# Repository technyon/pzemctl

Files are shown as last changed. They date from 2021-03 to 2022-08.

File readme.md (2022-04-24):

# pzem energy monitor firmware

# About

This is the source code for a three phase energy monitor based upon three pzem-004t modules. It reads energy values from those modules and sends them over LAN to an mqtt server. Optionally, values can be displayed on an SSD1306 display.
The included 3D printable space houses all required hardware.

# A word of caution

The pzem-004t modules used need to be connected to mains power. Mains power is dangerous and there's danger to receive a potentially lethal electric shock. Furthermore, fire can be the result of incorrectly connecting the modules.  Only connect the pzem-004t if you know what you are doing! If not, ask someone who does.

Also, please read the paragraph about liability in the provided LICENSE file.

# Hardware
### Required
- Arduino Mega 2560
- W5500 LAN Module (https://www.az-delivery.de/en/products/w5500-ethernet-netzwerk-internet-modul-fuer-arduino)

### Optional
- SSD1306 Display (https://www.amazon.de/gp/product/B0777HHQDT)
- Push buttons to control display (https://www.amazon.de/gp/product/B07DJ8QMB1). Other buttons can be used of course, Fusion 360 file is included to modify enclosure.
- Relay card to control external appliance
- 3 LEDs

# Compilation

### Prerequisites
- Arduino SDK. Unpack and set ARDUINO_SDK_PATH to its location (e. g. export ARDUINO_SDK_PATH="/usr/share/arduino-1.8.13/")
- Arduino cmake toolchain: https://github.com/a9183756-gh/Arduino-CMake-Toolchain/. Unpack to a location of your choice
- cmake
- avr-gcc

### Running cmake

In the pzemctl directory, create a cmake build directory in change into it.

- cmake -D CMAKE_TOOLCHAIN_FILE=/path/to/Arduino-CMake-Toolchain/Arduino-toolchain.cmake ..
- Run make

cmake should now be setup. Run make to compile.

# Wiring

- Connect pzem-004t modules to Mega uart ports 1-3 (Mega pins 14-19)
- connect W5500 LAN module to SPI PINS (Mega pins 50-53)
- connect W5500 CS pin to Mega Pin 53
- connect W5500 Reset pin to Mega Pin 49
- connect display to Mega I2C pins (optional; Mega pins 20 and 21)
- Connect LEDs to Mega pins 5-8 (optional; PIN 7 is for network status)
- Connect Buttons to GND and Mega pins 44-48 (optional)

# Enclosure

The enclosure is seperated into two levels. The bottom levels holds the pzem-004t modules. Use M3 ~4mm screws.
The upper layer has room for the Arduino mega and the W5500 module. Again, uses M3 screws. Optionally, 3 LEDs can be mounted here. They point inside the case, I used white PETG so they can shine through.
The lid allows to mount the display (use M2 screws and nut) and the buttons.

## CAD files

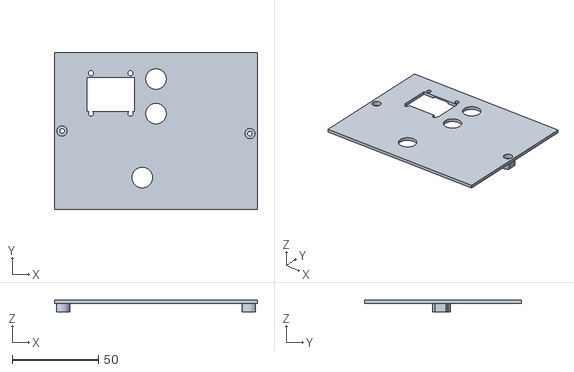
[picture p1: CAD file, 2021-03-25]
enclosure/pzem004t Top.stl
118.0 x 91.0 x 7.00

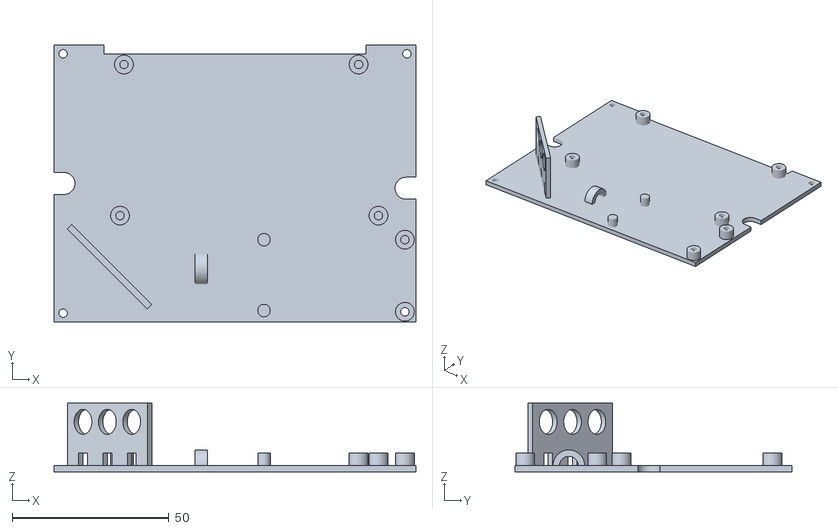
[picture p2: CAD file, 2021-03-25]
enclosure/pzem004t Middle.stl
115.6 x 88.6 x 22.0

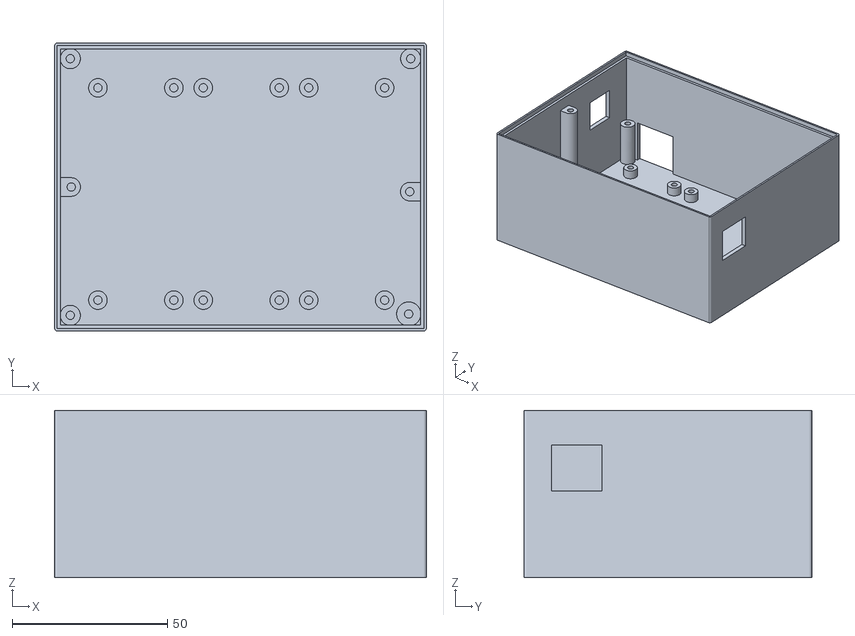
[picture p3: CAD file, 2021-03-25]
enclosure/pzem004t Bottom.stl
120.0 x 93.0 x 54.0

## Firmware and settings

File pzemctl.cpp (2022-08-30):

// Including Arduino.h is required for using Serial functions
#include <Arduino.h>
#include <SPI.h>
#include <HardwareSerial.h>
#include "Pzem004t.h"
#include "Network.h"
#include <src/Arduino_FreeRTOS.h>
#include <src/task.h>
#include "DisplaySSD1306.h"
#include "Led.h"
#include "Input.h"
#include "WebServer.h"
#include "EepromConfiguration.h"
#include "Config.h"


EepromConfiguration* configuration;
hw::Pzem004t* pzem;
hw::Input* input;
hw::DisplaySSD1306* display;
Network *nw;
web::WebServer* webServer;
hw::Led led;

hw::pzem004tvalues phasesCombined;
hw::pzem004tvalues phase1Values;
hw::pzem004tvalues phase2Values;
hw::pzem004tvalues phase3Values;

bool setupModeRequested = false;
bool setupModeEnabled = false;

bool switchState = false;
uint8_t displayUpdateCounter = 0;

void setupMode()
{
    setupModeEnabled = true;
    Serial.println(F("SETUP"));
    display->showMessage("Starting\nSetup");
    nw->enableConfigMode();

    IPAddress ip = nw->ipAddress();
    char message[18];
    sprintf(message, "%i.%i.%i.%i", ip[0], ip[1], ip[2], ip[3]);
    display->showMessage(message);

    webServer->enable();
    while(webServer->enabled() && setupModeEnabled)
    {
        vTaskDelay( 500 / portTICK_PERIOD_MS);
    }
    if(setupModeEnabled)
    {
        display->showMessage("Configu\nsaved");
    }
    else
    {
        display->showMessage("Setup\ncancelled");
    }

    webServer->disable();
    nw->disableConfigMode();
    vTaskDelay(2000 / portTICK_PERIOD_MS);
    display->clearMessage();

    setupModeEnabled = false;
}

void TaskPollPzem(void *pvParameters)
{
    while(true)
    {
        pzem->update();

        phase1Values = pzem->values1();
        phase2Values = pzem->values2();
        phase3Values = pzem->values3();

        phasesCombined.voltage = (phase1Values.voltage + phase2Values.voltage + phase3Values.voltage) / (float)3;
        phasesCombined.current = phase1Values.current + phase2Values.current + phase3Values.current;
        phasesCombined.power = phase1Values.power + phase2Values.power + phase3Values.power;
        phasesCombined.energy = phase1Values.energy + phase2Values.energy + phase3Values.energy;
        phasesCombined.frequency = (phase1Values.frequency + phase2Values.frequency + phase3Values.frequency) / (float)3;
        phasesCombined.pf = (phase1Values.pf + phase2Values.pf + phase3Values.pf) / 3;
        phasesCombined.error = phase1Values.error || phase2Values.error || phase3Values.error;

        vTaskDelay( 100 / portTICK_PERIOD_MS);
    }
}

void TaskInputAndDisplay(void *pvParameters)
{
    while(true)
    {
        input->update();
        displayUpdateCounter++;
        if(displayUpdateCounter >= 4)
        {
            displayUpdateCounter = 0;
            display->update(phasesCombined, phase1Values, phase2Values, phase3Values);
        }
        vTaskDelay( 20 / portTICK_PERIOD_MS);
    }
}

void TaskNetwork(void *pvParameters)
{
    while(true)
    {
        webServer->update();
        nw->update(phasesCombined, phase1Values, phase2Values, phase3Values);

        vTaskDelay( 100 / portTICK_PERIOD_MS);
    }
}

void TaskSetupMode(void *pvParameters)
{
    while(true)
    {
        if(setupModeRequested)
        {
            setupModeRequested = false;
            if(!setupModeEnabled)
            {
                setupMode();
            }
        }

        vTaskDelay( 200 / portTICK_PERIOD_MS);
    }
}

void setupTasks()
{
    xTaskCreate(
            TaskPollPzem
            ,  "Pzm"
            ,  64
            ,  NULL
            ,  2
            ,  NULL );

    xTaskCreate(
            TaskInputAndDisplay
            ,  "Dsp"
            ,  256
            ,  NULL
            ,  0
            ,  NULL );

    xTaskCreate(
            TaskNetwork
            ,  "Nw"
            ,  1024
            ,  NULL
            ,  1
            ,  NULL );

    xTaskCreate(
            TaskSetupMode
            ,  "Setup"
            ,  448
            ,  NULL
            ,  0
            ,  NULL );
}

void setSwitchState(bool value, bool showMessage)
{
    if(switchState == value) return;

    switchState = value;
    digitalWrite(SWITCH_PIN, switchState);
    led.setBrightnessSwitchState(switchState ? 255 : 0);
    if(showMessage)
    {
        if (switchState)
        {
            display->showMessage("\n       ON", 1000);
        } else
        {
            display->showMessage("\n      OFF", 1000);
        }
    }
}

void buttonPressed(hw::ButtonId buttonId)
{
    switch(buttonId)
    {
        case hw::ButtonId::SwitchPhase:
            display->switchPhase();
            nw->publishPhase(display->selectedPhase());
            break;
        case hw::ButtonId::SwitchPhaseLong:
        {
            if(setupModeEnabled)
            {
                setupModeEnabled = false;
            }
            else
            {
                setupModeRequested = true;
            }

            break;
        }
        case hw::ButtonId::SwitchView:
            display->switchView();
            nw->publishView((int)display->selectedView() - 1);
            break;
        case hw::ButtonId::SwitchOnOff:
            setSwitchState(!switchState, true);
            nw->publishSwitchState(switchState);
            break;

    }
}

void configurationChanged()
{
    nw->configurationChanged();
}

void onNetworkEventReceived(const NetworkEvent& event)
{
    switch(event.type)
    {
        case NetworkEventType::viewChange:
            display->changeView(event.paramInt);
            break;
        case NetworkEventType::phaseChange:
            display->changePhase(event.paramInt);
            break;
        case NetworkEventType::switchStateChange:
            setSwitchState(event.paramBool, true);
            break;
        case NetworkEventType::resetEnergy:
            pzem->resetEnergy();
            display->showMessage("Energy\nreset");
            vTaskDelay( 1000 / portTICK_PERIOD_MS);
            display->clearMessage();
            break;
        case NetworkEventType::customViewValue1Changed:
        {
            hw::ViewConfiguration viewConfiguration = display->customViewConfiguration();
            viewConfiguration.value1 = (hw::ViewValueType) event.paramInt;
            display->setCustomViewConfiguration(viewConfiguration);
            break;
        }
        case NetworkEventType::customViewValue2Changed:
        {
            hw::ViewConfiguration viewConfiguration = display->customViewConfiguration();
            viewConfiguration.value2 = (hw::ViewValueType) event.paramInt;
            display->setCustomViewConfiguration(viewConfiguration);
            break;
        }
        case NetworkEventType::customViewValue3Changed:
        {
            hw::ViewConfiguration viewConfiguration = display->customViewConfiguration();
            viewConfiguration.value3 = (hw::ViewValueType) event.paramInt;
            display->setCustomViewConfiguration(viewConfiguration);
            break;
        }
        case NetworkEventType::phase1OffsetChanged:
        {
            display->setEnergyOffsetPhase1(event.paramFloat);
            break;
        }
        case NetworkEventType::phase2OffsetChanged:
        {
            display->setEnergyOffsetPhase2(event.paramFloat);
            break;
        }
        case NetworkEventType::phase3OffsetChanged:
        {
            display->setEnergyOffsetPhase3(event.paramFloat);
            break;
        }
        default:
            Serial.print(F("Unhandled network event type: "));
            Serial.print((int) event.type);
            Serial.println();
            break;
    }
}

void setup()
{
	Serial.begin(9600);
    Serial.println(F("Start"));

    randomSeed(analogRead(0) + analogRead(1) + analogRead(2));

    configuration = new EepromConfiguration(configurationChanged);

    input = new hw::Input(buttonPressed);
    nw = new Network(configuration, onNetworkEventReceived);
    webServer = new web::WebServer(nw->ethernetClient(), configuration);

    input->initialize();

    hw::ViewConfiguration viewConfiguration;
    viewConfiguration.value1 = hw::ViewValueType::Voltage;
    viewConfiguration.value2 = hw::ViewValueType::Current;
    viewConfiguration.value3 = hw::ViewValueType::PowerFactor;

    display = new hw::DisplaySSD1306();
    display->initialize();
    display->setCustomViewConfiguration(viewConfiguration);
    led.initialize();

    pinMode(SWITCH_PIN, OUTPUT);
    setSwitchState(true, false);

    pzem = new hw::Pzem004t(&Serial1, &Serial2, &Serial3);
    nw->initialize();

	setupTasks();

    setupModeRequested = !configuration->hasValidSignature();
}

void loop()
{

}

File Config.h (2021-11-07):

#pragma once

// pzem004t
#define PZEM1_ADDRESS 0xf8
#define PZEM2_ADDRESS 0xf8
#define PZEM3_ADDRESS 0xf8

// LEDs
#define LED1_PIN 5
#define LED2_PIN 6
#define LED3_PIN 7
#define LED4_PIN 8

// Input
#define SWITCH_PHASE_PIN 44
#define SWITCH_VIEW_PIN 46
#define SWITCH_ON_OFF_PIN 48
#define LONG_PRESS_THRESHOLD 1000

// Switch
#define SWITCH_PIN 30

// Ethernet
#define ETHERNET_CS_PIN 53
#define ETHERNET_RESET_PIN 49

// MQTT
#define phase1VoltageTopic "energy/phase1/voltage"
#define phase1CurrentTopic "energy/phase1/current"
#define phase1PowerTopic "energy/phase1/power"
#define phase1EnergyTopic  "energy/phase1/energy"
#define phase1FrequencyTopic "energy/phase1/frequency"
#define phase1PowerFactorTopic "energy/phase1/powerfactor"
#define phase1EnergyOffsetTopic  "energy/phase1/energyOffset"
#define phase1ErrorTopic "energy/phase1/error"

#define phase2VoltageTopic  "energy/phase2/voltage"
#define phase2CurrentTopic "energy/phase2/current"
#define phase2PowerTopic "energy/phase2/power"
#define phase2EnergyTopic  "energy/phase2/energy"
#define phase2FrequencyTopic "energy/phase2/frequency"
#define phase2PowerFactorTopic "energy/phase2/powerfactor"
#define phase2EnergyOffsetTopic  "energy/phase2/energyOffset"
#define phase2ErrorTopic "energy/phase2/error"

#define phase3VoltageTopic  "energy/phase3/voltage"
#define phase3CurrentTopic "energy/phase3/current"
#define phase3PowerTopic "energy/phase3/power"
#define phase3EnergyTopic  "energy/phase3/energy"
#define phase3FrequencyTopic "energy/phase3/frequency"
#define phase3PowerFactorTopic "energy/phase3/powerfactor"
#define phase3EnergyOffsetTopic  "energy/phase3/energyOffset"
#define phase3ErrorTopic "energy/phase3/error"

#define phasesCombinedVoltageTopic  "energy/phasesCombined/voltage"
#define phasesCombinedCurrentTopic "energy/phasesCombined/current"
#define phasesCombinedPowerTopic "energy/phasesCombined/power"
#define phasesCombinedEnergyTopic  "energy/phasesCombined/energy"
#define phasesCombinedFrequencyTopic "energy/phasesCombined/frequency"
#define phasesCombinedPowerFactorTopic "energy/phasesCombined/powerfactor"
#define phasesCombinedErrorTopic "energy/phasesCombined/error"

#define led1BrightnessTopic  "energy/control/led1Brightness"
#define led2BrightnessTopic  "energy/control/led2Brightness"
#define selectedViewTopic  "energy/control/view"
#define selectedPhaseTopic  "energy/control/phase"
#define switchStateTopic  "energy/control/switchState"
#define resetEnergyTopic  "energy/control/resetEnergy"
#define reconnectCountTopic  "energy/control/reconnectCount"
#define customViewValue1Topic  "energy/control/customValue1"
#define customViewValue2Topic  "energy/control/customValue2"
#define customViewValue3Topic  "energy/control/customValue3"

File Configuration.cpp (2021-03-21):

#include "Configuration.h"
#include <EEPROM.h>
#include <string.h>
#include <Arduino.h>

Configuration::Configuration(void (*callback)())
: _callback(callback)
{
    initialize();

    Serial.println(mqttServerAddress);
    Serial.println(dnsServerAddress);
    Serial.println(gatewayAddress);
    Serial.println(ipAddress);
    Serial.println(subnetMask);
}

void Configuration::initialize()
{
    for(int i=0; i < sizeof(mqttServerAddress); i++)
    {
        mqttServerAddress[i] = 0;
    }
    for(int i=0; i < sizeof(dnsServerAddress); i++)
    {
        dnsServerAddress[i] = 0;
    }
    for(int i=0; i < sizeof(gatewayAddress); i++)
    {
        gatewayAddress[i] = 0;
    }
    for(int i=0; i < sizeof(ipAddress); i++)
    {
        ipAddress[i] = 0;
    }
    for(int i=0; i < sizeof(subnetMask); i++)
    {
        subnetMask[i] = 0;
    }
    for(int i=0; i < sizeof(mac); i++)
    {
        mac[i] = 0;
    }
    for(int i=0; i < sizeof(mqttPublishInterval); i++)
    {
        mqttPublishInterval[i] = 0;
    }

    readEeprom();
}


void Configuration::readEeprom()
{
    if(!hasValidSignature())
    {
        Serial.println(F("No valid signature found in eeprom."));
        generateMacAddress();
        return;
    }

    for(int i=0; i < sizeof(mqttServerAddress); i++)
    {
        mqttServerAddress[i] = EEPROM[MQTT_EEPROM_OFFSET + i];
    }
    for(int i=0; i < sizeof(dnsServerAddress); i++)
    {
        dnsServerAddress[i] = EEPROM[DNS_EEPROM_OFFSET + i];
    }
    for(int i=0; i < sizeof(gatewayAddress); i++)
    {
        gatewayAddress[i] = EEPROM[GATEWAY_EEPROM_OFFSET + i];
    }
    for(int i=0; i < sizeof(ipAddress); i++)
    {
        ipAddress[i] = EEPROM[IP_EEPROM_OFFSET + i];
    }
    for(int i=0; i < sizeof(subnetMask); i++)
    {
        subnetMask[i] = EEPROM[SUBNET_MASK_OFFSET + i];
    }
    for(int i=0; i < sizeof(mac); i++)
    {
        mac[i] = EEPROM[MAC_OFFSET + i];
    }
    for(int i=0; i < sizeof(mqttPublishInterval); i++)
    {
        mqttPublishInterval[i] = EEPROM[MQTT_PUBLISH_INTERVAL + i];
    }
    parseMqttPublishInterval();
}

void Configuration::writeEeprom()
{
    Serial.println(F("Write EEPROM"));

    Serial.println(mqttServerAddress);
    Serial.println(dnsServerAddress);
    Serial.println(gatewayAddress);
    Serial.println(ipAddress);
    Serial.println(subnetMask);

    Serial.println(F(" --"));

    if(!hasValidSignature())
    {
        writeSignature();
    }

    for(int i=0; i < sizeof(mqttServerAddress); i++)
    {
        EEPROM.update(MQTT_EEPROM_OFFSET + i, mqttServerAddress[i]);
    }
    for(int i=0; i < sizeof(dnsServerAddress); i++)
    {
        EEPROM.update(DNS_EEPROM_OFFSET + i, dnsServerAddress[i]);
    }
    for(int i=0; i < sizeof(gatewayAddress); i++)
    {
        EEPROM.update(GATEWAY_EEPROM_OFFSET + i, gatewayAddress[i]);
    }
    for(int i=0; i < sizeof(ipAddress); i++)
    {
        EEPROM.update(IP_EEPROM_OFFSET + i, ipAddress[i]);
    }
    for(int i=0; i < sizeof(subnetMask); i++)
    {
        EEPROM.update(SUBNET_MASK_OFFSET + i, subnetMask[i]);
    }
    for(int i=0; i < sizeof(mac); i++)
    {
        EEPROM.update(MAC_OFFSET + i, mac[i]);
    }
    for(int i=0; i < sizeof(mqttPublishInterval); i++)
    {
        EEPROM.update(MQTT_PUBLISH_INTERVAL + i, mqttPublishInterval[i]);
    }

    parseMqttPublishInterval();

    _callback();
}

void Configuration::writeSignature()
{
    char sig[] = "pzem004t";
    for(int i=0; i < 9; i++)
    {
        EEPROM.update(i, sig[i]);
    }
}

bool Configuration::hasValidSignature()
{
    char sig[9];
    for(int i=0; i<9; i++)
    {
        sig[i] = EEPROM[i];
    }

    return strcmp(sig, "pzem004t") == 0;
}

void Configuration::generateMacAddress()
{
    mac[0] = 0x00;  // wiznet prefix
    mac[1] = 0x08;  // wiznet prefix
    mac[2] = 0xDC;  // wiznet prefix
    mac[3] = random(0,255);
    mac[4] = random(0,255);
    mac[5] = random(0,255);
}

void Configuration::clearEeprom()
{
    for (int i = 0 ; i < EEPROM.length() ; i++)
    {
        EEPROM.update(i, 0);
    }
}

void Configuration::parseMqttPublishInterval()
{
    _numericMqttPublishInterval = max(atoi(mqttPublishInterval), 200);
}

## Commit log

2021-03-07 user correct serial ports
    [pzemctl.cpp]
2021-03-12 don't pass reset pin as parameter
2021-03-14 add LED network status
2021-03-14 add led control
2021-03-16 add button input
2021-03-16 add phase switching via button
2021-03-17 add view switching
2021-03-19 add web interface for configuration
    [Configuration.h]
2021-03-19 use config values from eeprom for network configuration
    [Configuration.h]
2021-03-19 use config values from eeprom
    [Configuration.h]
2021-03-20 dynamic graph scaling
    [Configuration.h]
2021-03-20 Revert "dynamic graph scaling"
    This reverts commit 59c31ab5
    [Configuration.h]
2021-03-20 add more controllable LEDs
2021-03-20 remove LED task
2021-03-20 constrain mqtt server address to 40 chars
    [Configuration.h]
2021-03-20 publish switch state on mqtt
2021-03-20 allow setting switch state via mqtt
2021-03-20 allow configuring publish interval
    [Configuration.h]
2021-03-20 fix parsing of mqtt payload
    [Led.cpp, Network.cpp]
2021-03-21 fix parsing of mqtt switch state message
    [Network.cpp, pzemctl.cpp]
2021-03-21 display refactoring
    [Configuration.h]
2021-03-21 allow custom view config via mqtt
    [Configuration.h]
2021-03-21 add reconnect count
    [Configuration.h]
2021-03-22 also publish power on mqtt
2021-03-23 restore phases combined power calculation
2021-03-23 move SWITCH_PIN to Config.h
2021-03-25 add enclosure files
    [pzem004t Bottom.stl, pzem004t Middle.stl, pzem004t Top.stl]
2021-03-26 improve max current determination
2021-04-02 fix graph display fix
    [pzemctl.cpp]
2021-11-07 publish pzem module error via mqtt
    [Config.h, Network.cpp, pzemctl.cpp]
2022-04-10 fix link in readme to arduino cmake toolchain
2022-04-10 set arduino board in cmakelist
2022-08-30 fix timestamp data type
    [Network.cpp]
